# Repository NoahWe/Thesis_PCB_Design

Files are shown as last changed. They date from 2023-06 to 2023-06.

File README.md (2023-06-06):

# Experiment
This repository contains the PCB designs for a pressure sensor array using BMP581 sensors which will be used during an experiment as part of my MSc thesis. The experiment aims to determine the pressure distribution over a wing, located behind tilting rotors. The sensor array is specifically aimed at the vehicle designed by Alessandro Mancinelli (https://doi.org/10.1109/ICUAS54217.2022.9836063), and is supposed to resolve some of the problems experienced using tilt-rotors to roll.

## How to get started
1. Clone the repository
2. Open one of the KiCad project files (.kicad_pro).

The mainboard is located in /Experiment_PCB/MainBoard/. The sensor strips connected to the top half of the wing are located in Experiment_PCB/SensorStrip_Top/, and finally the sensor strip connected to the bottom half of the wing are located in /Experiment_PCB/SensorStrip_Bottom/.

## Sensors
The sensor which will be used for the experiment is the BMP581: https://www.bosch-sensortec.com/products/environmental-sensors/pressure-sensors/bmp581/

The setup will have 72 pressure sensors which will be driven by a single Teensy4.1 board (https://www.pjrc.com/store/teensy41.html). The Teensy4.1 features 2 SPI buses allowing me to use a single chip select line to drive two sensors. The SPI buses will run at approximately 5 MHz.

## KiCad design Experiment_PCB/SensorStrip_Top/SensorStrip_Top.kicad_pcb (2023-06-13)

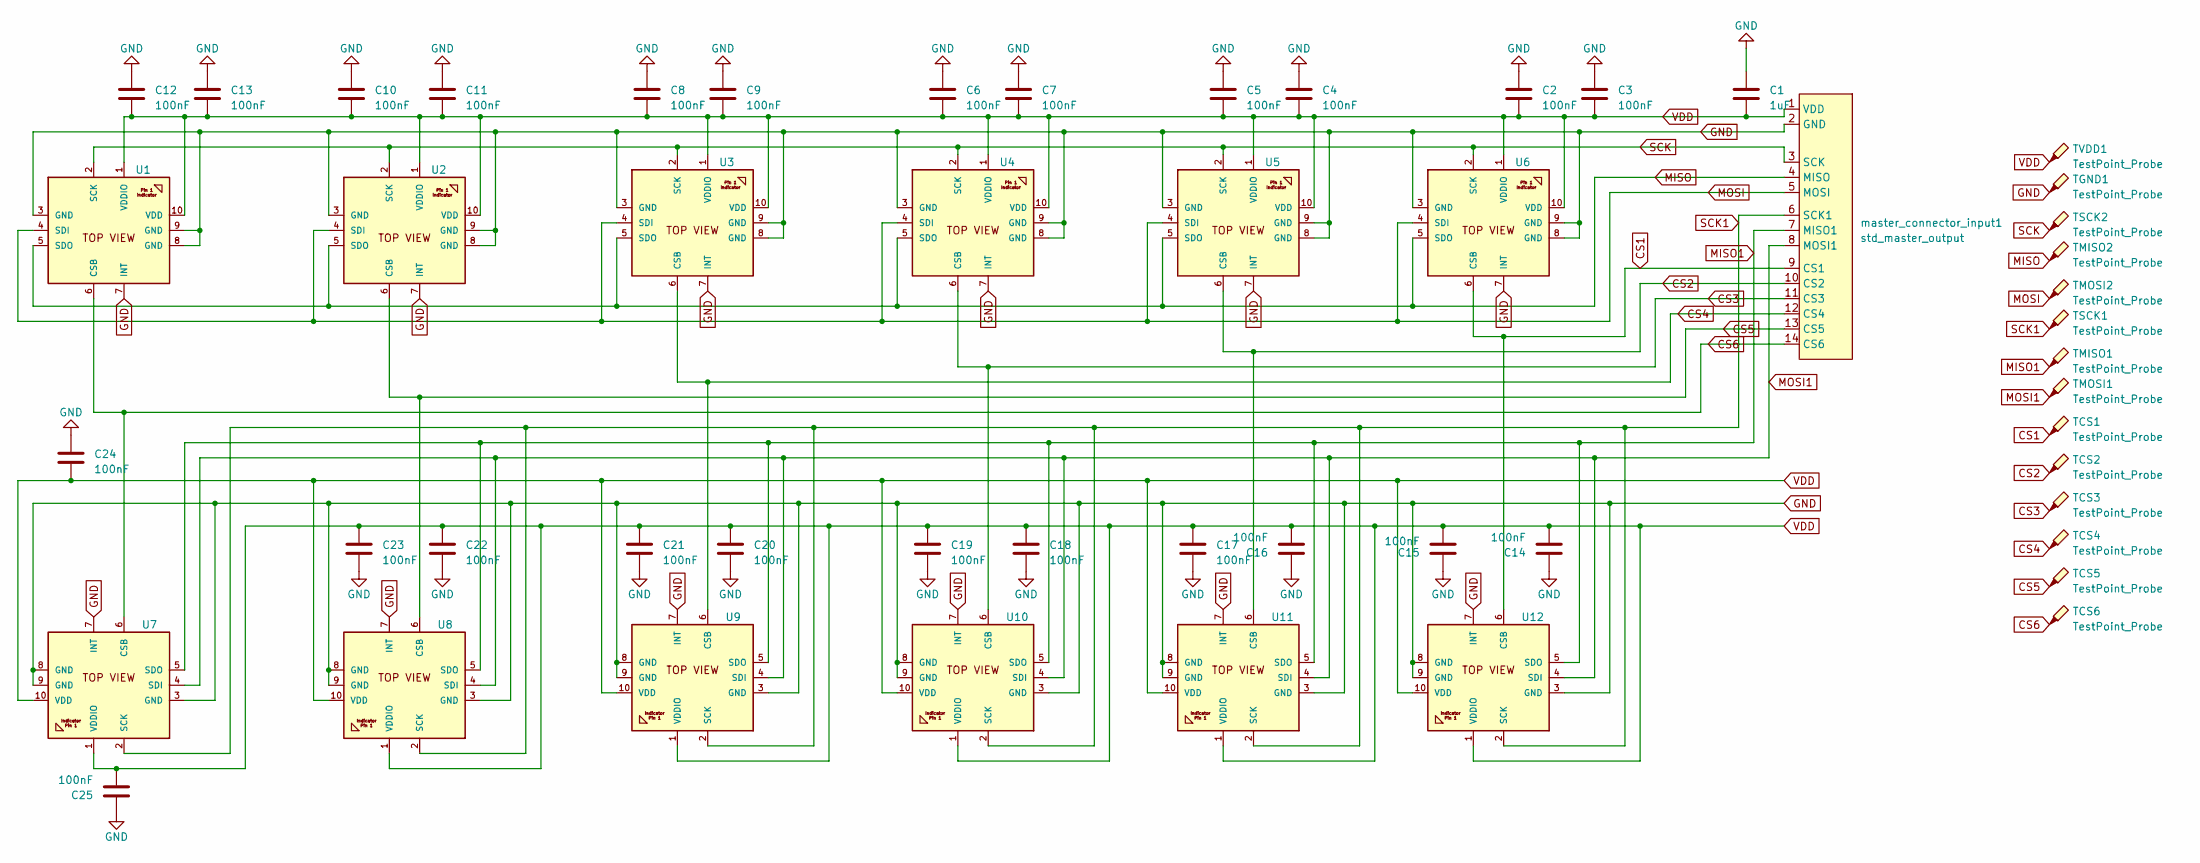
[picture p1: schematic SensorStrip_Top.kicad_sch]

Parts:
C1: 1uF; C_0603_1608Metric
C2, C3, C4, C5, C6, C7, C8, C9, C10, C11, C12, C13, C14, C15, C16, C17, C18, C19, C20, C21, C22, C23, C24, C25: 100nF; C_0201_0603Metric
TCS1, TCS2, TCS3, TCS4, TCS5, TCS6: TestPoint_Probe; TestPoint_Pad_1.0x1.0mm
TGND1: TestPoint_Probe; TestPoint_Pad_1.0x1.0mm
TMISO1, TMISO2: TestPoint_Probe; TestPoint_Pad_1.0x1.0mm
TMOSI1, TMOSI2: TestPoint_Probe; TestPoint_Pad_1.0x1.0mm
TSCK1, TSCK2: TestPoint_Probe; TestPoint_Pad_1.0x1.0mm
TVDD1: TestPoint_Probe; TestPoint_Pad_1.0x1.0mm
U1, U2, U3, U4, U5, U6, U7, U8, U9, U10, U11, U12: BMP581_Landing_Pattern
master_connector_input1: std_master_output; Strip_pins_top

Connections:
CS1: TCS1.1, U6.6 (CSB), U12.6 (CSB), master_connector_input1.9 (CS1)
CS2: TCS2.1, U5.6 (CSB), U11.6 (CSB), master_connector_input1.10 (CS2)
CS3: TCS3.1, U4.6 (CSB), U10.6 (CSB), master_connector_input1.11 (CS3)
CS4: TCS4.1, U3.6 (CSB), U9.6 (CSB), master_connector_input1.12 (CS4)
CS5: TCS5.1, U2.6 (CSB), U8.6 (CSB), master_connector_input1.13 (CS5)
CS6: TCS6.1, U1.6 (CSB), U7.6 (CSB), master_connector_input1.14 (CS6)
GND: C1.1, C2.1, C3.1, C4.1, C5.1, C6.1, C7.1, C8.1, C9.1, C10.1, C11.1, C12.1, C13.1, C14.1, C15.1, C16.1, C17.1, C18.1, C19.1, C20.1, C21.1, C22.1, C23.1, C24.1, C25.1, TGND1.1, U1.3 (GND), U1.7 (INT), U1.8 (GND), U1.9 (GND), U2.3 (GND), U2.7 (INT), U2.8 (GND), U2.9 (GND), U3.3 (GND), U3.7 (INT), U3.8 (GND), U3.9 (GND), U4.3 (GND), U4.7 (INT), U4.8 (GND), U4.9 (GND), U5.3 (GND), U5.7 (INT), U5.8 (GND), U5.9 (GND), U6.3 (GND), U6.7 (INT), U6.8 (GND), U6.9 (GND), U7.3 (GND), U7.7 (INT), U7.8 (GND), U7.9 (GND), U8.3 (GND), U8.7 (INT), U8.8 (GND), U8.9 (GND), U9.3 (GND), U9.7 (INT), U9.8 (GND), U9.9 (GND), U10.3 (GND), U10.7 (INT), U10.8 (GND), U10.9 (GND), U11.3 (GND), U11.7 (INT), U11.8 (GND), U11.9 (GND), U12.3 (GND), U12.7 (INT), U12.8 (GND), U12.9 (GND), master_connector_input1.2 (GND)
MISO: TMISO2.1, U1.5 (SDO), U2.5 (SDO), U3.5 (SDO), U4.5 (SDO), U5.5 (SDO), U6.5 (SDO), master_connector_input1.4 (MISO)
MISO1: TMISO1.1, U7.5 (SDO), U8.5 (SDO), U9.5 (SDO), U10.5 (SDO), U11.5 (SDO), U12.5 (SDO), master_connector_input1.7 (MISO1)
MOSI: TMOSI2.1, U1.4 (SDI), U2.4 (SDI), U3.4 (SDI), U4.4 (SDI), U5.4 (SDI), U6.4 (SDI), master_connector_input1.5 (MOSI)
MOSI1: TMOSI1.1, U7.4 (SDI), U8.4 (SDI), U9.4 (SDI), U10.4 (SDI), U11.4 (SDI), U12.4 (SDI), master_connector_input1.8 (MOSI1)
SCK: TSCK2.1, U1.2 (SCK), U2.2 (SCK), U3.2 (SCK), U4.2 (SCK), U5.2 (SCK), U6.2 (SCK), master_connector_input1.3 (SCK)
SCK1: TSCK1.1, U7.2 (SCK), U8.2 (SCK), U9.2 (SCK), U10.2 (SCK), U11.2 (SCK), U12.2 (SCK), master_connector_input1.6 (SCK1)
VDD: C1.2, C2.2, C3.2, C4.2, C5.2, C6.2, C7.2, C8.2, C9.2, C10.2, C11.2, C12.2, C13.2, C14.2, C15.2, C16.2, C17.2, C18.2, C19.2, C20.2, C21.2, C22.2, C23.2, C24.2, C25.2, TVDD1.1, U1.1 (VDDIO), U1.10 (VDD), U2.1 (VDDIO), U2.10 (VDD), U3.1 (VDDIO), U3.10 (VDD), U4.1 (VDDIO), U4.10 (VDD), U5.1 (VDDIO), U5.10 (VDD), U6.1 (VDDIO), U6.10 (VDD), U7.1 (VDDIO), U7.10 (VDD), U8.1 (VDDIO), U8.10 (VDD), U9.1 (VDDIO), U9.10 (VDD), U10.1 (VDDIO), U10.10 (VDD), U11.1 (VDDIO), U11.10 (VDD), U12.1 (VDDIO), U12.10 (VDD), master_connector_input1.1 (VDD)

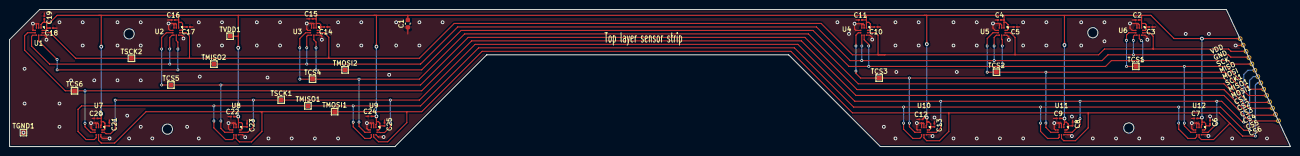
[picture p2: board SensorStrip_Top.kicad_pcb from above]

Board: 2 copper layers, 275.8 x 29.5 mm, 52 parts (0 on the bottom side), 14 nets.

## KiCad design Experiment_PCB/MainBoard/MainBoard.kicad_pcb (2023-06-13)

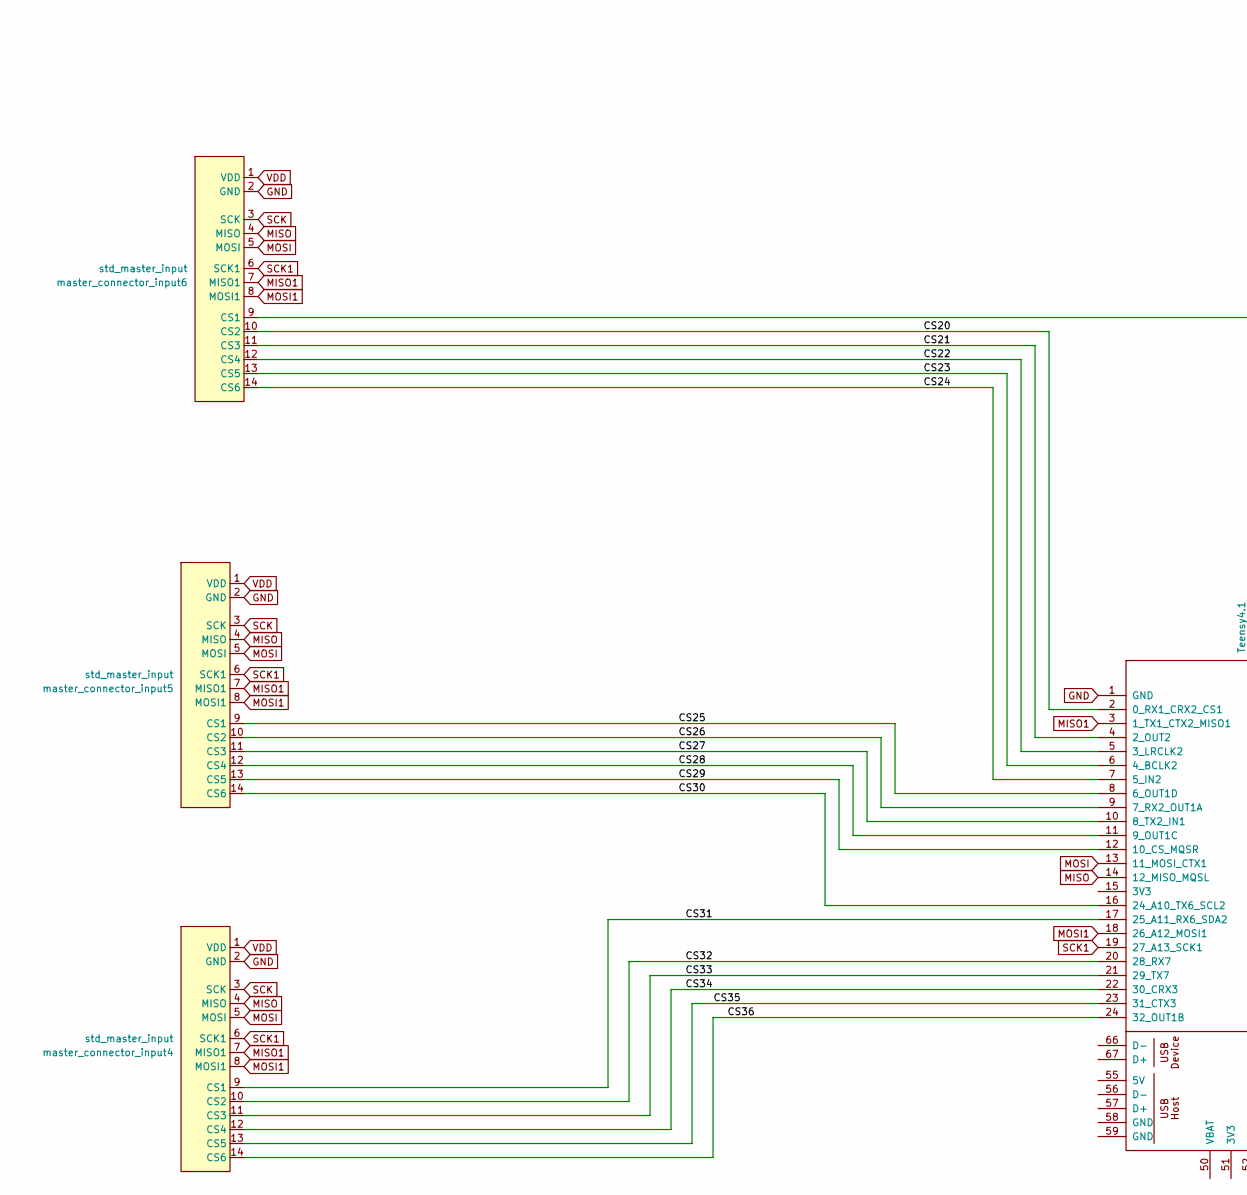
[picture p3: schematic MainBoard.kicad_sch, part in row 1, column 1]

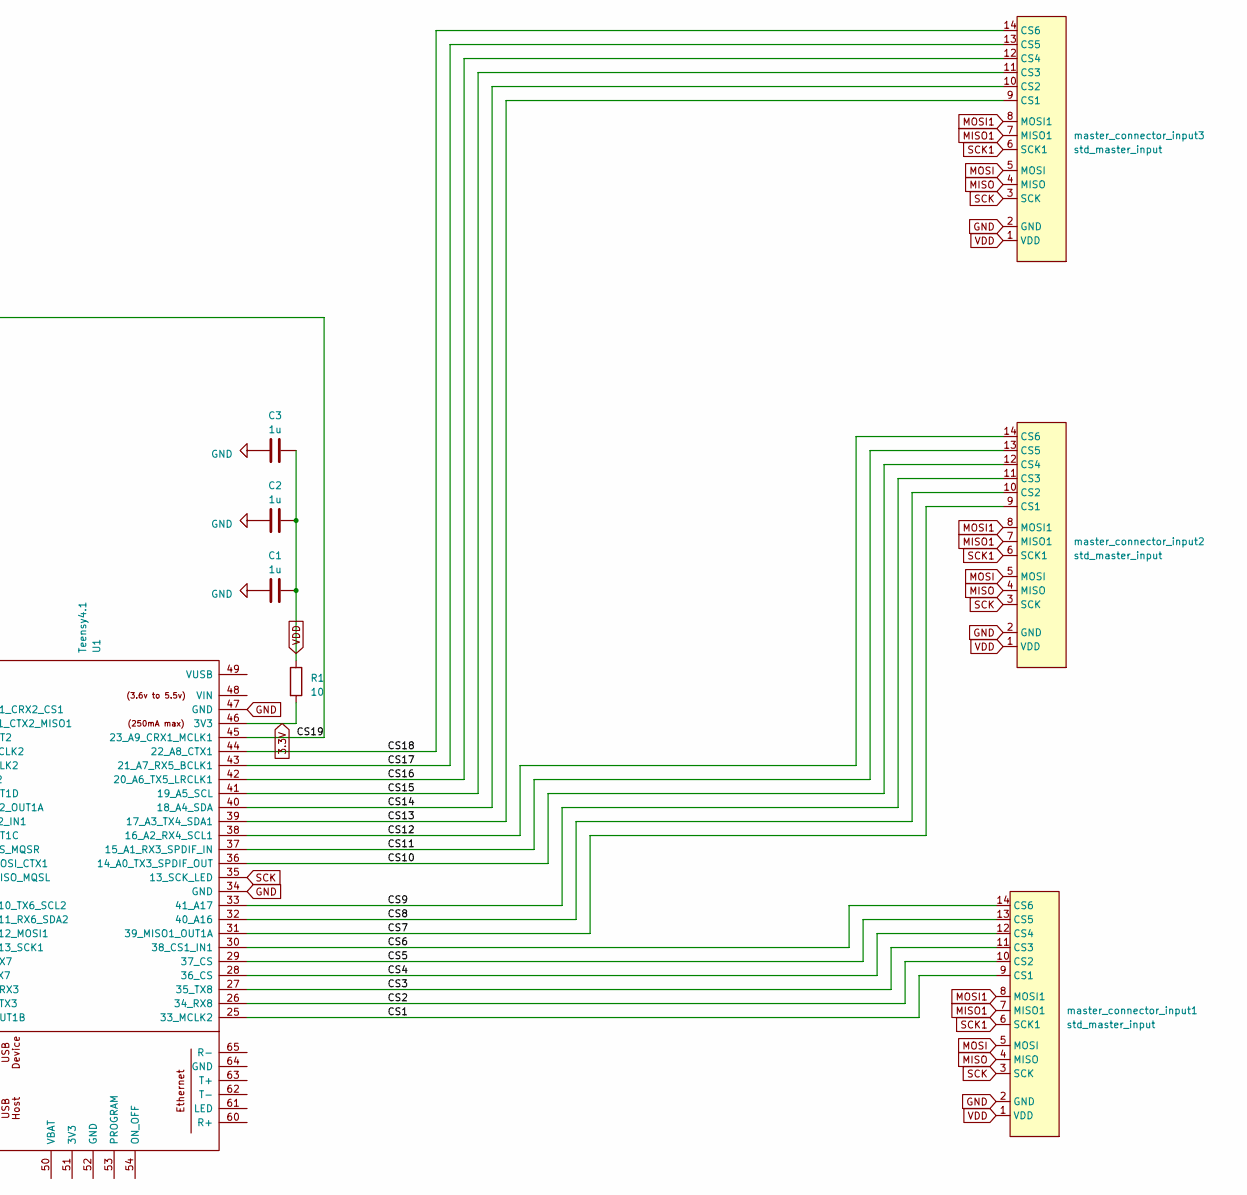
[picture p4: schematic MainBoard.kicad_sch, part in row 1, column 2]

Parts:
C1, C2, C3: 1u; C_0603_1608Metric
R1: 10; R_0402_1005Metric
U1: Teensy4.1; Teensy41
master_connector_input1, master_connector_input3, master_connector_input5: std_master_input; Master_pins_top
master_connector_input2, master_connector_input4, master_connector_input6: std_master_input; Master_pins_bottom

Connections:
3.3V: R1.2, U1.46 (3V3)
/CS1: U1.25 (33_MCLK2), master_connector_input1.9 (CS1)
/CS2: U1.26 (34_RX8), master_connector_input1.10 (CS2)
/CS3: U1.27 (35_TX8), master_connector_input1.11 (CS3)
/CS4: U1.28 (36_CS), master_connector_input1.12 (CS4)
/CS5: U1.29 (37_CS), master_connector_input1.13 (CS5)
/CS6: U1.30 (38_CS1_IN1), master_connector_input1.14 (CS6)
/CS7: U1.31 (39_MISO1_OUT1A), master_connector_input2.9 (CS1)
/CS8: U1.32 (40_A16), master_connector_input2.10 (CS2)
/CS9: U1.33 (41_A17), master_connector_input2.11 (CS3)
/CS10: U1.36 (14_A0_TX3_SPDIF_OUT), master_connector_input2.12 (CS4)
/CS11: U1.37 (15_A1_RX3_SPDIF_IN), master_connector_input2.13 (CS5)
/CS12: U1.38 (16_A2_RX4_SCL1), master_connector_input2.14 (CS6)
/CS13: U1.39 (17_A3_TX4_SDA1), master_connector_input3.9 (CS1)
/CS14: U1.40 (18_A4_SDA), master_connector_input3.10 (CS2)
/CS15: U1.41 (19_A5_SCL), master_connector_input3.11 (CS3)
/CS16: U1.42 (20_A6_TX5_LRCLK1), master_connector_input3.12 (CS4)
/CS17: U1.43 (21_A7_RX5_BCLK1), master_connector_input3.13 (CS5)
/CS18: U1.44 (22_A8_CTX1), master_connector_input3.14 (CS6)
/CS19: U1.45 (23_A9_CRX1_MCLK1), master_connector_input6.9 (CS1)
/CS20: U1.2 (0_RX1_CRX2_CS1), master_connector_input6.10 (CS2)
/CS21: U1.4 (2_OUT2), master_connector_input6.11 (CS3)
/CS22: U1.5 (3_LRCLK2), master_connector_input6.12 (CS4)
/CS23: U1.6 (4_BCLK2), master_connector_input6.13 (CS5)
/CS24: U1.7 (5_IN2), master_connector_input6.14 (CS6)
/CS25: U1.8 (6_OUT1D), master_connector_input5.9 (CS1)
/CS26: U1.9 (7_RX2_OUT1A), master_connector_input5.10 (CS2)
/CS27: U1.10 (8_TX2_IN1), master_connector_input5.11 (CS3)
/CS28: U1.11 (9_OUT1C), master_connector_input5.12 (CS4)
/CS29: U1.12 (10_CS_MQSR), master_connector_input5.13 (CS5)
/CS30: U1.16 (24_A10_TX6_SCL2), master_connector_input5.14 (CS6)
/CS31: U1.17 (25_A11_RX6_SDA2), master_connector_input4.9 (CS1)
/CS32: U1.20 (28_RX7), master_connector_input4.10 (CS2)
/CS33: U1.21 (29_TX7), master_connector_input4.11 (CS3)
/CS34: U1.22 (30_CRX3), master_connector_input4.12 (CS4)
/CS35: U1.23 (31_CTX3), master_connector_input4.13 (CS5)
/CS36: U1.24 (32_OUT1B), master_connector_input4.14 (CS6)
GND: C1.1, C2.1, C3.1, U1.1 (GND), U1.34 (GND), U1.47 (GND), master_connector_input1.2 (GND), master_connector_input2.2 (GND), master_connector_input3.2 (GND), master_connector_input4.2 (GND), master_connector_input5.2 (GND), master_connector_input6.2 (GND)
MISO: U1.14 (12_MISO_MQSL), master_connector_input1.4 (MISO), master_connector_input2.4 (MISO), master_connector_input3.4 (MISO), master_connector_input4.4 (MISO), master_connector_input5.4 (MISO), master_connector_input6.4 (MISO)
MISO1: U1.3 (1_TX1_CTX2_MISO1), master_connector_input1.7 (MISO1), master_connector_input2.7 (MISO1), master_connector_input3.7 (MISO1), master_connector_input4.7 (MISO1), master_connector_input5.7 (MISO1), master_connector_input6.7 (MISO1)
MOSI: U1.13 (11_MOSI_CTX1), master_connector_input1.5 (MOSI), master_connector_input2.5 (MOSI), master_connector_input3.5 (MOSI), master_connector_input4.5 (MOSI), master_connector_input5.5 (MOSI), master_connector_input6.5 (MOSI)
MOSI1: U1.18 (26_A12_MOSI1), master_connector_input1.8 (MOSI1), master_connector_input2.8 (MOSI1), master_connector_input3.8 (MOSI1), master_connector_input4.8 (MOSI1), master_connector_input5.8 (MOSI1), master_connector_input6.8 (MOSI1)
SCK: U1.35 (13_SCK_LED), master_connector_input1.3 (SCK), master_connector_input2.3 (SCK), master_connector_input3.3 (SCK), master_connector_input4.3 (SCK), master_connector_input5.3 (SCK), master_connector_input6.3 (SCK)
SCK1: U1.19 (27_A13_SCK1), master_connector_input1.6 (SCK1), master_connector_input2.6 (SCK1), master_connector_input3.6 (SCK1), master_connector_input4.6 (SCK1), master_connector_input5.6 (SCK1), master_connector_input6.6 (SCK1)
VDD: C1.2, C2.2, C3.2, R1.1, master_connector_input1.1 (VDD), master_connector_input2.1 (VDD), master_connector_input3.1 (VDD), master_connector_input4.1 (VDD), master_connector_input5.1 (VDD), master_connector_input6.1 (VDD)

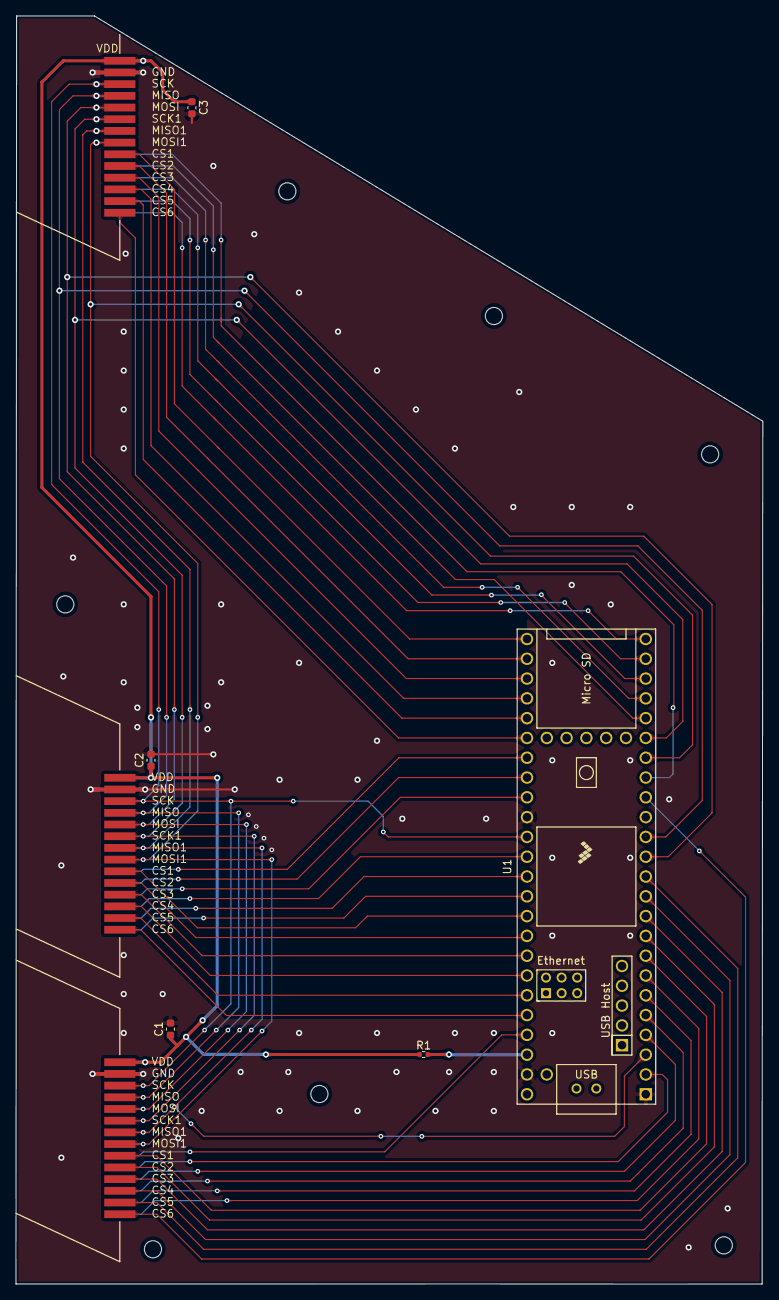
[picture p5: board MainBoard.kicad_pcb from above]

Board: 2 copper layers, 95.8 x 162.7 mm, 11 parts (0 on the bottom side), 45 nets.

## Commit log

2023-05-15 Added Teensy submodule
2023-05-17 started pcb development
    [BMP581_PCB.kicad_pcb, BMP581_PCB.kicad_sch, MainBoard.kicad_pcb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]
2023-05-18 New footprint submodule + progress
    [SensorStrip_Bottom.kicad_pcb, SensorStrip_Bottom.kicad_sch, SensorStrip_Top.kicad_sch]
2023-05-22 update strips
    [MainBoard.kicad_pcb, MainBoard.kicad_sch, SensorStrip_Bottom.kicad_pcb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]
2023-06-01 Top sensor strip completed v1
    [SensorStrip_Top.kicad_pcb, SensorStrip_Top.kicad_sch, SensorStrip_Top_Single.kicad_pcb]
2023-06-05 All PCBs v1
    [BMP581_PCB.kicad_pcb, BMP581_PCB.kicad_sch, MainBoard.kicad_pcb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]
2023-06-06 Incorporate feedback
    [MainBoard.kicad_pcb, MainBoard.kicad_sch, SensorStrip_Bottom.kicad_pcb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]
2023-06-07 update for file transfer / cleanup some traces
    [MainBoard.kicad_pcb, MainBoard.kicad_sch, SensorStrip_Bottom.kicad_pcb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]
2023-06-08 added gerber and drill files to ignore list
2023-06-08 transfer files to laptop for order
    [MainBoard.kicad_pcb, SensorStrip_Bottom.kicad_pcb, SensorStrip_Top.kicad_pcb]
2023-06-13 Ordered PCBs
    [MainBoard.kicad_pcb, SensorStrip_Bottom.kicad_pcb, SensorStrip_Top.kicad_pcb]
